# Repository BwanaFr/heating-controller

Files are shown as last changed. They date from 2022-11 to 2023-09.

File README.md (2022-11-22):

# Heating controller

## Presentation
This project is a IOT hardware heater controller for floor heat cumulating heaters (not sure about english term).
These heaters where mainly installed in France.
The principle is to store heat in the concrete floor during nights (when nuclear plants are free) to be restored during the day.

The heater can be controlled using MQTT using a Wi-Fi connection or using the integrated OLED display.
It is designed to be mounted on a DIN rail in an electrical cabinet.

## Hardware
Hardware design files are located in the hardware folder.
Schematics and PCB is designed using Kicad.

# Software
Microcontroller firmware is located in the software folder.
This is a PlatformIO project.

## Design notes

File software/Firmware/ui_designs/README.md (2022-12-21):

# About icons
Icons use in this project comes from Google Material Symbols [https://fonts.google.com/icons]

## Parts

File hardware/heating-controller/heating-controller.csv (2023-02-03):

Source: | C:\Temp\heating-controller\hardware\heating-controller\heating-controller.kicad_sch
Date: | 13/01/2023 11:20:34
Tool: | Eeschema (6.0.9)
Generator: | C:\Program Files\KiCad\6.0\bin\scripting\plugins/bom_csv_grouped_by_value.py
Component Count: | 36
Individual Components:
Item | Qty | Reference(s) | Value | LibPart | Footprint | Datasheet | Power | Type
 |  | C1 | 10uF | Device:C_Polarized | Capacitor_SMD:C_0805_2012Metric | ~
 |  | C2 | 10uF | Device:C_Polarized | Capacitor_SMD:C_0805_2012Metric | ~
 |  | C3 | 4.7uF | Device:C_Polarized | Capacitor_SMD:C_1206_3216Metric | ~
 |  | C4 | 1uF | Device:C | Capacitor_SMD:C_0603_1608Metric | ~
 |  | C5 | 150uF | Device:C_Polarized | Capacitor_THT:C_Radial_D10.0mm_H12.5mm_P5.00mm | ~
 |  | D1 | 1N4148WS | Diode:1N4148WS | Diode_SMD:D_SOD-323 | https://www.vishay.com/docs/85751/1n4148ws.pdf
 |  | D2 | LED | Device:LED_Small | LED_SMD:LED_0805_2012Metric | ~
 |  | D3 | ESD7371HT1G | Diode:SMF7V0A | Diode_SMD:D_SOD-323_HandSoldering | https://www.vishay.com/doc?85881
 |  | D4 | 1N4148WS | Diode:1N4148WS | Diode_SMD:D_SOD-323 | https://www.vishay.com/docs/85751/1n4148ws.pdf
 |  | F1 | T1A/300V | Device:Fuse | Fuse:Fuse_Littelfuse_372_D8.50mm | ~
 |  | F2 | T1A/300V | Device:Fuse | Fuse:Fuse_Littelfuse_372_D8.50mm | ~
 |  | J1 | Temperature_probes | Connector:Screw_Terminal_01x04 | TerminalBlock_Phoenix:TerminalBlock_Phoenix_MKDS-3-4-5.08_1x04_P5.08mm_Horizontal | ~
 |  | J2 | LilyGo T-Display S3 | Connector:Conn_01x12_Male | Connector_PinHeader_2.54mm:PinHeader_1x12_P2.54mm_Vertical | ~
 |  | J3 | Power connector | Connector:Screw_Terminal_01x07 | TerminalBlock_Phoenix:TerminalBlock_Phoenix_MKDS-3-7-5.08_1x07_P5.08mm_Horizontal | ~
 |  | J4 | EXT_LED | Connector_Generic:Conn_01x02 | Connector_PinHeader_2.54mm:PinHeader_1x02_P2.54mm_Vertical | ~
 |  | J5 | USER_LED | Connector_Generic:Conn_01x02 | Connector_PinHeader_2.54mm:PinHeader_1x02_P2.54mm_Vertical | ~
 |  | K1 | FINDER-32.21-x000 | Relay:FINDER-32.21-x000 | Relay_THT:Relay_SPDT_Finder_32.21-x000 | https://gfinder.findernet.com/assets/Series/355/S32EN.pdf
 |  | PS1 | AMEM5-5S277HAVZ | heating-controller:AMEM5-5S277HAVZ | heating-controller:Converter_ACDC_aimtec_AMEM5 | https://aimtec.com/site/Aimtec/files/Datasheet/HighResolution/amem5-277havz.pdf
 |  | Q1 | AO3400A | Transistor_FET:AO3400A | Package_TO_SOT_SMD:SOT-23 | http://www.aosmd.com/pdfs/datasheet/AO3400A.pdf
 |  | Q2 | AO3400A | Transistor_FET:AO3400A | Package_TO_SOT_SMD:SOT-23 | http://www.aosmd.com/pdfs/datasheet/AO3400A.pdf
 |  | R1 | 15k | Device:R | Resistor_SMD:R_0603_1608Metric | ~
 |  | R2 | 100k | Device:R | Resistor_THT:R_Axial_DIN0204_L3.6mm_D1.6mm_P5.08mm_Horizontal | ~
 |  | R3 | 100k | Device:R | Resistor_THT:R_Axial_DIN0204_L3.6mm_D1.6mm_P5.08mm_Horizontal | ~
 |  | R4 | 15k | Device:R | Resistor_SMD:R_0603_1608Metric | ~
 |  | R5 | 12 | Device:R | Resistor_THT:R_Axial_DIN0614_L14.3mm_D5.7mm_P15.24mm_Horizontal | ~ | 3W | Wirewound
 |  | R6 | 4.7k | Device:R | Resistor_SMD:R_0603_1608Metric | ~
 |  | R7 | 470 | Device:R | Resistor_SMD:R_0603_1608Metric | ~
 |  | R8 | 1k | Device:R | Resistor_SMD:R_0603_1608Metric | ~
 |  | R9 | 1k | Device:R | Resistor_SMD:R_0603_1608Metric | ~
 |  | R10 | 470 | Device:R | Resistor_SMD:R_0603_1608Metric | ~
 |  | R11 | 100k | Device:R | Resistor_SMD:R_0603_1608Metric | ~
 |  | R12 | 100k | Device:R | Resistor_SMD:R_0603_1608Metric | ~
 |  | R13 | 470 | Device:R | Resistor_SMD:R_0603_1608Metric | ~
 |  | RV1 | ERZE10A561 | Device:Varistor | Varistor:RV_Disc_D12mm_W7.5mm_P7.5mm | ~
 |  | RV2 | ERZE10A561 | Device:Varistor | Varistor:RV_Disc_D12mm_W7.5mm_P7.5mm | ~
 |  | U1 | H11AA1 | Isolator:H11AA1 | Package_DIP:DIP-6_W7.62mm | https://www.vishay.com/docs/83608/h11aa1.pdf
Collated Components:
Item | Qty | Reference(s) | Value | LibPart | Footprint | Datasheet | Power | Type
1 | 2 | C1, C2 | 10uF | Device:C_Polarized | Capacitor_SMD:C_0805_2012Metric | ~
2 | 1 | C3 | 4.7uF | Device:C_Polarized | Capacitor_SMD:C_1206_3216Metric | ~
3 | 1 | C4 | 1uF | Device:C | Capacitor_SMD:C_0603_1608Metric | ~
4 | 1 | C5 | 150uF | Device:C_Polarized | Capacitor_THT:C_Radial_D10.0mm_H12.5mm_P5.00mm | ~
5 | 2 | D1, D4 | 1N4148WS | Diode:1N4148WS | Diode_SMD:D_SOD-323 | https://www.vishay.com/docs/85751/1n4148ws.pdf
6 | 1 | D2 | LED | Device:LED_Small | LED_SMD:LED_0805_2012Metric | ~
7 | 1 | D3 | ESD7371HT1G | Diode:SMF7V0A | Diode_SMD:D_SOD-323_HandSoldering | https://www.vishay.com/doc?85881
8 | 2 | F1, F2 | T1A/300V | Device:Fuse | Fuse:Fuse_Littelfuse_372_D8.50mm | ~
9 | 1 | J1 | Temperature_probes | Connector:Screw_Terminal_01x04 | TerminalBlock_Phoenix:TerminalBlock_Phoenix_MKDS-3-4-5.08_1x04_P5.08mm_Horizontal | ~
10 | 1 | J2 | LilyGo T-Display S3 | Connector:Conn_01x12_Male | Connector_PinHeader_2.54mm:PinHeader_1x12_P2.54mm_Vertical | ~
11 | 1 | J3 | Power connector | Connector:Screw_Terminal_01x07 | TerminalBlock_Phoenix:TerminalBlock_Phoenix_MKDS-3-7-5.08_1x07_P5.08mm_Horizontal | ~
12 | 1 | J4 | EXT_LED | Connector_Generic:Conn_01x02 | Connector_PinHeader_2.54mm:PinHeader_1x02_P2.54mm_Vertical | ~
13 | 1 | J5 | USER_LED | Connector_Generic:Conn_01x02 | Connector_PinHeader_2.54mm:PinHeader_1x02_P2.54mm_Vertical | ~
14 | 1 | K1 | FINDER-32.21-x000 | Relay:FINDER-32.21-x000 | Relay_THT:Relay_SPDT_Finder_32.21-x000 | https://gfinder.findernet.com/assets/Series/355/S32EN.pdf
15 | 1 | PS1 | AMEM5-5S277HAVZ | heating-controller:AMEM5-5S277HAVZ | heating-controller:Converter_ACDC_aimtec_AMEM5 | https://aimtec.com/site/Aimtec/files/Datasheet/HighResolution/amem5-277havz.pdf
16 | 2 | Q1, Q2 | AO3400A | Transistor_FET:AO3400A | Package_TO_SOT_SMD:SOT-23 | http://www.aosmd.com/pdfs/datasheet/AO3400A.pdf
17 | 2 | R1, R4 | 15k | Device:R | Resistor_SMD:R_0603_1608Metric | ~
18 | 2 | R2, R3 | 100k | Device:R | Resistor_THT:R_Axial_DIN0204_L3.6mm_D1.6mm_P5.08mm_Horizontal | ~
19 | 1 | R5 | 12 | Device:R | Resistor_THT:R_Axial_DIN0614_L14.3mm_D5.7mm_P15.24mm_Horizontal | ~ | 3W | Wirewound
20 | 1 | R6 | 4.7k | Device:R | Resistor_SMD:R_0603_1608Metric | ~
21 | 3 | R7, R10, R13 | 470 | Device:R | Resistor_SMD:R_0603_1608Metric | ~
22 | 2 | R8, R9 | 1k | Device:R | Resistor_SMD:R_0603_1608Metric | ~
23 | 2 | R11, R12 | 100k | Device:R | Resistor_SMD:R_0603_1608Metric | ~
24 | 2 | RV1, RV2 | ERZE10A561 | Device:Varistor | Varistor:RV_Disc_D12mm_W7.5mm_P7.5mm | ~
25 | 1 | U1 | H11AA1 | Isolator:H11AA1 | Package_DIP:DIP-6_W7.62mm | https://www.vishay.com/docs/83608/h11aa1.pdf

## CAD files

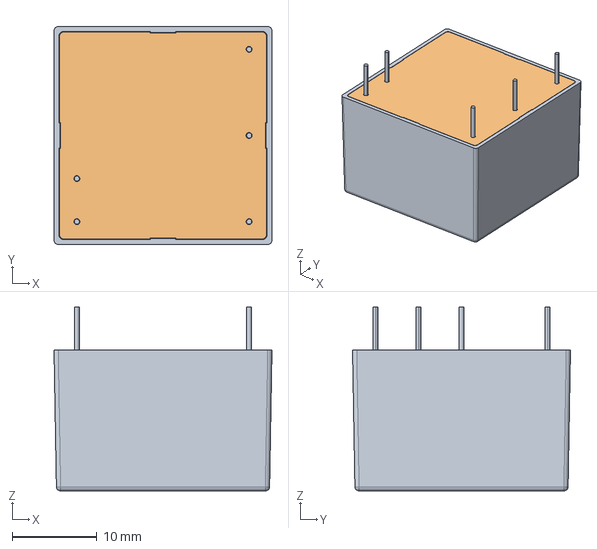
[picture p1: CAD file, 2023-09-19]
hardware/3d_models/tmps_05-105.stp
25.7 x 25.7 x 21.7 mm

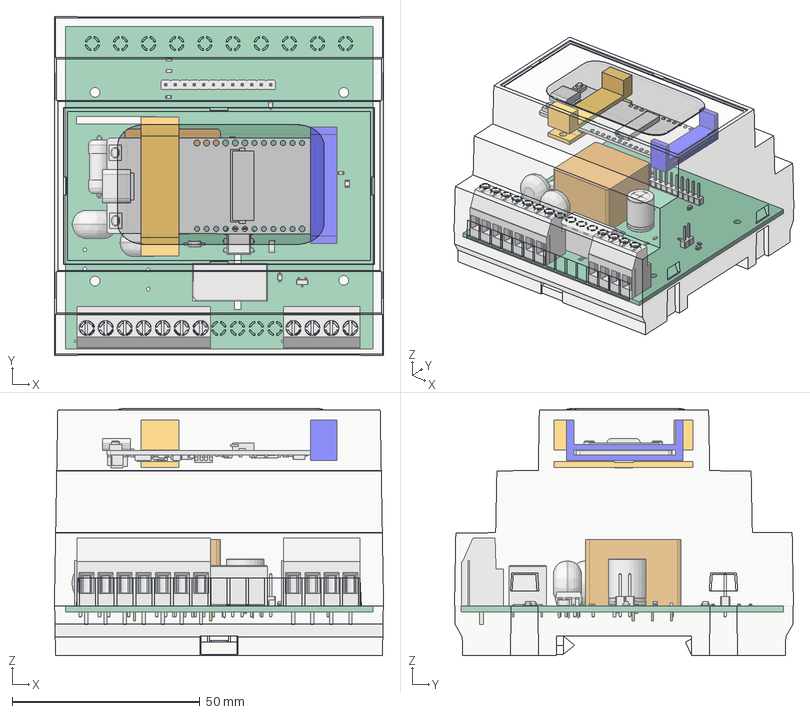
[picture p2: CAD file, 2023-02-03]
hardware/heating-controller-integration.FCStd
87.6 x 90.2 x 65.8 mm
NFP190B-01A_9_2_1
S-WATCH_TOUCH-SCREEN_15_1_1
T_DISPLAY_S3
Pcb_2b62
R6_R_0603_1608Metric_a486fa5abdc1 x 7
PS1_Pad001_cc960fdde001
C3_C_Radial_D100mm_H125mm_P500mm_71014cd09946
RV1_RV_Disc_D12mm_W75mm_P75mm_a3a09b8d229c x 2
J2_PinHeader_1x12_P254mm_Vertical_862bfcde2853
J3_TerminalBlock_Phoenix_MKDS_3_7_508_1x07_P508mm_Horizontal_bc2887fb8af6
D3_LED_0805_2012Metric_4455ae678b20
C1_C_1206_3216Metric_184f41baba65
D1_D_SOD_323_aa465fcb5bed x 3
K1_Relay_SPDT_Finder_32.21-x000_b01d047eb10a
J4_PinHeader_1x02_P254mm_Vertical_cb93ea696dab
C2_C_0603_1608Metric_af71e0b8cedf
J1_TerminalBlock_Phoenix_MKDS_3_4_508_1x04_P508mm_Horizontal_3f8e2a9aea9a
R5_R_Axial_DIN0614_L143mm_D57mm_P1524mm_Horizontal_10cb85c8e1dd
R3_R_Axial_DIN0204_L36mm_D16mm_P508mm_Horizontal_2cfa1f32dbe2 x 2
U1_DIP-6_W7.62mm_9f37de575c71
Q1_SOT_23_480f1ca98e1c
Support_antenna
Support_PCB
Support_PCB_top

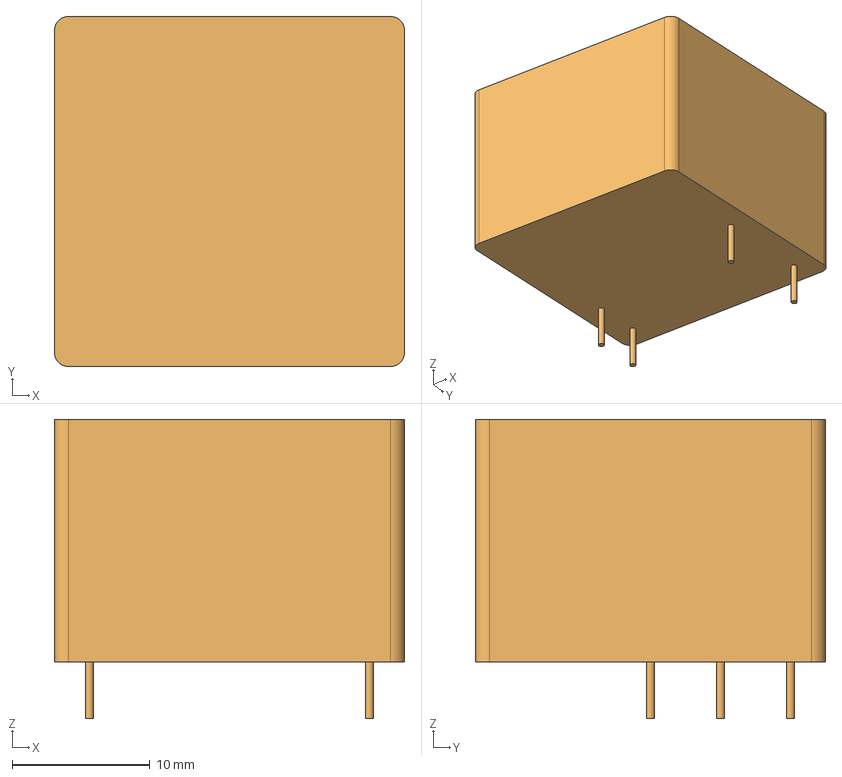
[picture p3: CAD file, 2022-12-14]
hardware/heating-controller/3d/Converter_ACDC_aimtec_AMEM5.step
25.4 x 25.4 x 21.7 mm

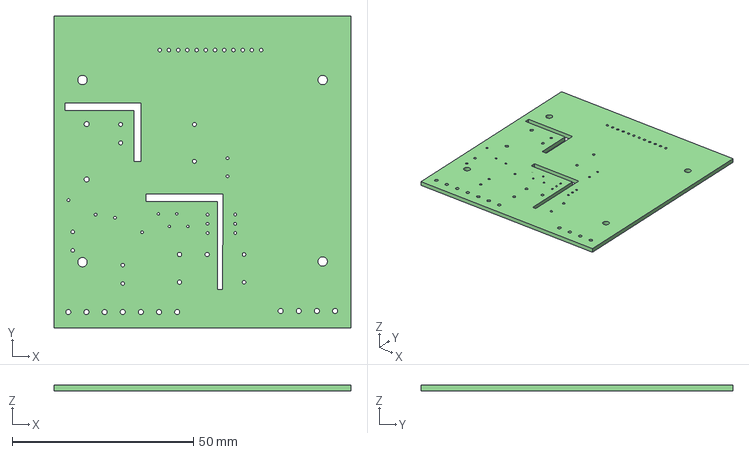
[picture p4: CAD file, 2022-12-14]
hardware/heating-controller/heating-controller.step
81.8 x 85.9 x 1.60 mm

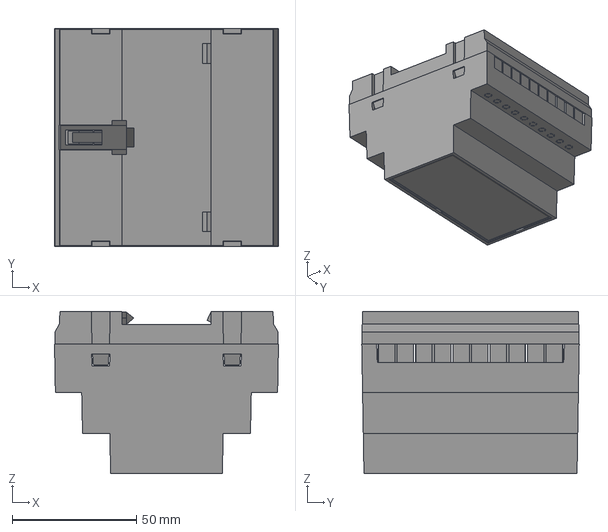
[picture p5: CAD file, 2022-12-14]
hardware/3d_models/z109_1.step
90.2 x 87.6 x 65.4 mm

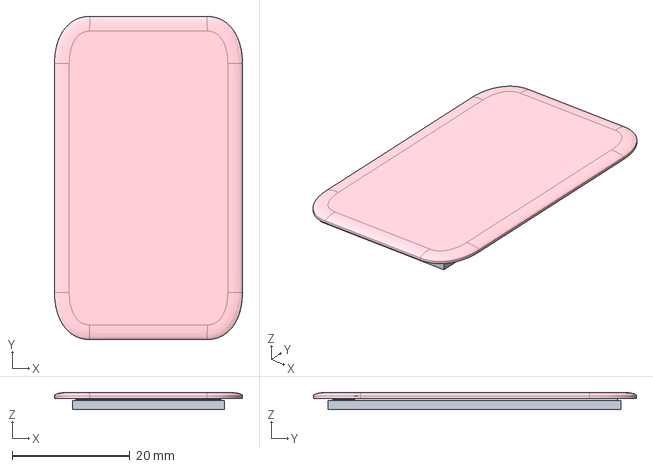
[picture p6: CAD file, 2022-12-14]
hardware/3d_models/glass_screen.stp
32.0 x 55.0 x 2.93 mm
NFP190B-01A_9_2_1
S-WATCH_TOUCH-SCREEN_15_1_1

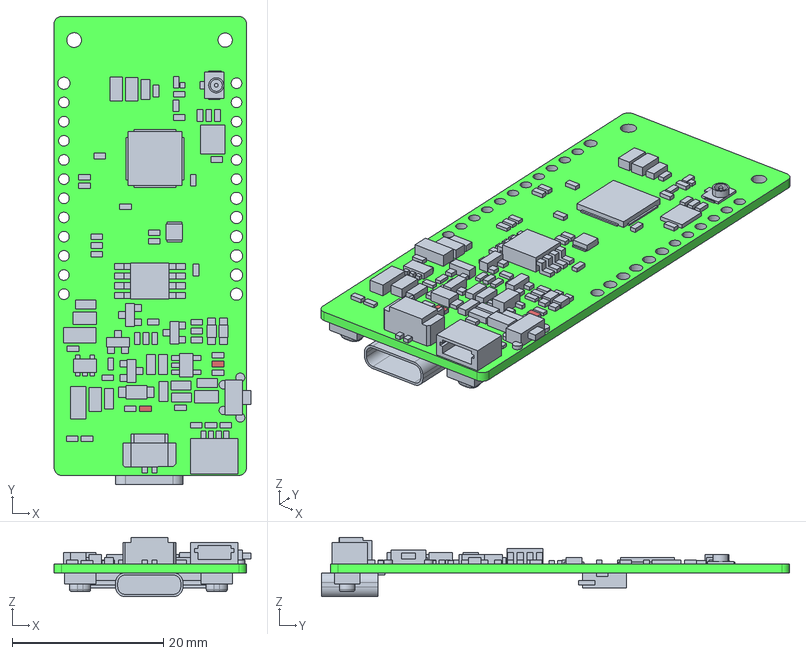
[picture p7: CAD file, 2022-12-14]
hardware/3d_models/t_display_s3.stp
26.1 x 62.0 x 7.86 mm

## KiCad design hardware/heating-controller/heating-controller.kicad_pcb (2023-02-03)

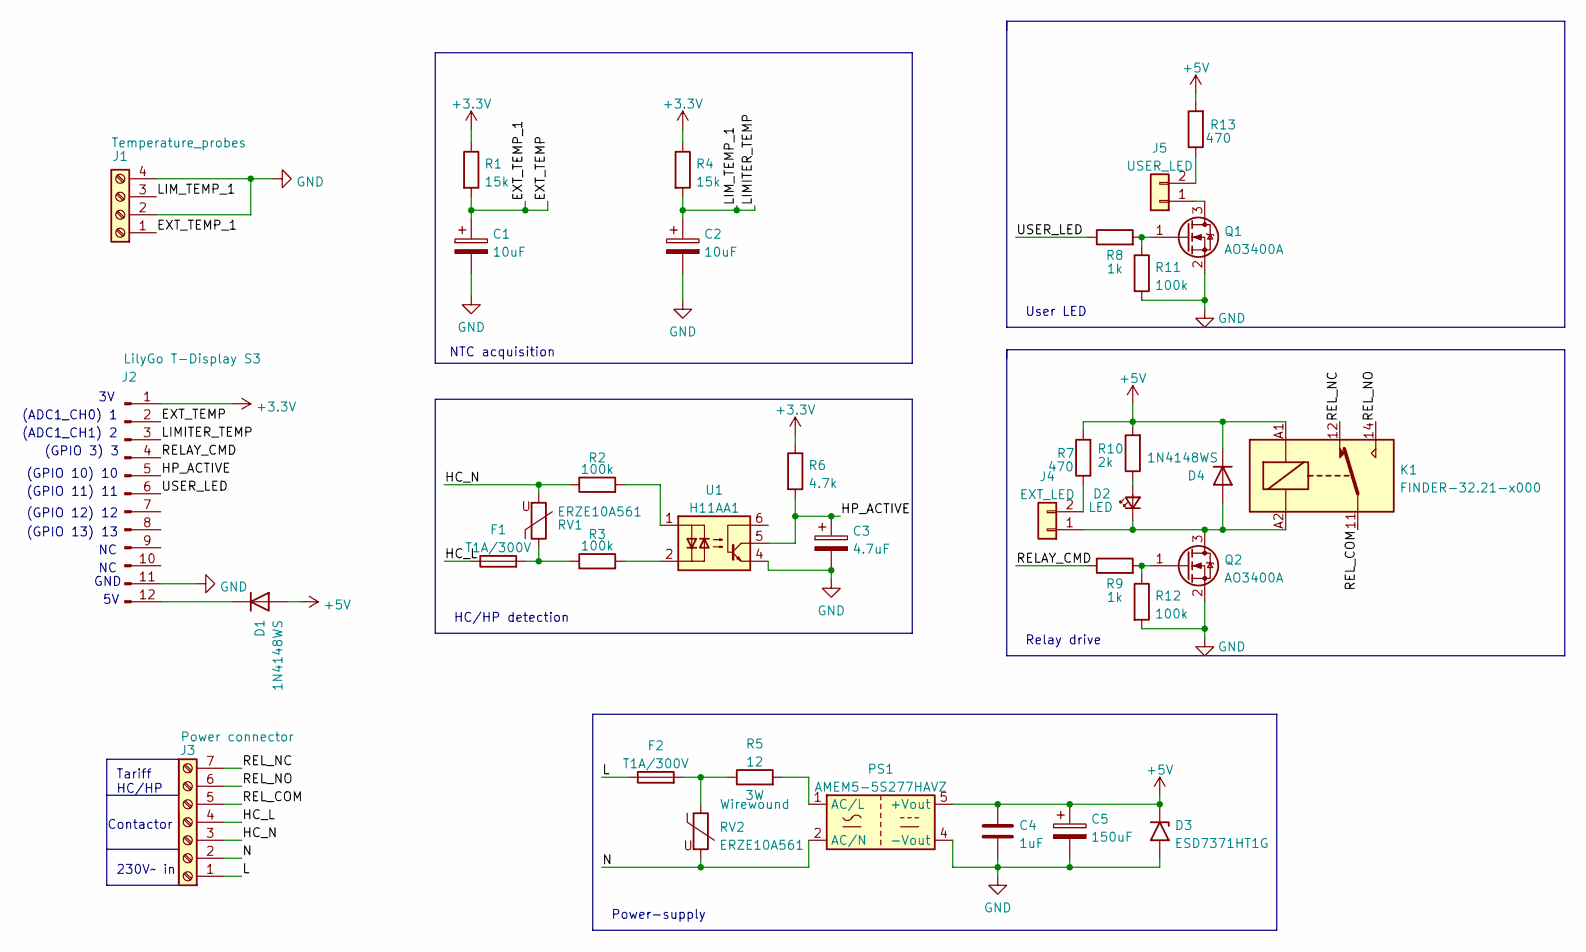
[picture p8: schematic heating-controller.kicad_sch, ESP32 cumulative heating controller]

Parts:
C1, C2: 10uF; C_0805_2012Metric
C3: 4.7uF; C_1206_3216Metric
C4: 1uF; C_0603_1608Metric
C5: 150uF; C_Radial_D10.0mm_H12.5mm_P5.00mm
D1, D4: 1N4148WS; D_SOD-323
D2: LED; LED_0805_2012Metric
D3: ESD7371HT1G; D_SOD-323_HandSoldering
F1, F2: T1A/300V; Fuse_Littelfuse_372_D8.50mm
J1: Temperature_probes; TerminalBlock_Phoenix_MKDS-3-4-5.08_1x04_P5.08mm_Horizontal
J2: LilyGo T-Display S3; PinHeader_1x12_P2.54mm_Vertical
J3: Power connector; TerminalBlock_Phoenix_MKDS-3-7-5.08_1x07_P5.08mm_Horizontal
J4: EXT_LED; PinHeader_1x02_P2.54mm_Vertical
J5: USER_LED; PinHeader_1x02_P2.54mm_Vertical
K1: FINDER-32.21-x000; Relay_SPDT_Finder_32.21-x000
PS1: AMEM5-5S277HAVZ; Converter_ACDC_aimtec_AMEM5
Q1, Q2: AO3400A; SOT-23
R1, R4: 15k; R_0603_1608Metric
R2, R3: 100k; R_Axial_DIN0204_L3.6mm_D1.6mm_P5.08mm_Horizontal
R5: 12; R_Axial_DIN0614_L14.3mm_D5.7mm_P15.24mm_Horizontal
R6: 4.7k; R_0603_1608Metric
R7, R13: 470; R_0603_1608Metric
R8, R9: 1k; R_0603_1608Metric
R10: 2k; R_0603_1608Metric
R11, R12: 100k; R_0603_1608Metric
RV1, RV2: ERZE10A561; RV_Disc_D12mm_W7.5mm_P7.5mm
U1: H11AA1; DIP-6_W7.62mm

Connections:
+3.3V: J2.1, R1.1, R4.1, R6.1
+5V: C4.1, C5.1, D1.2 (A), D3.1 (A1), D4.1 (K), K1.A1, PS1.5 (+Vout), R7.2, R10.2, R13.2
/EXT_TEMP: C1.1, J1.1, J2.2, R1.2
/HC_L: F1.1, J3.4
/HC_N: J3.3, R2.1, RV1.2
/HP_ACTIVE: C3.1, J2.5, R6.2, U1.5
/L: F2.1, J3.1
/LIMITER_TEMP: C2.1, J1.3, J2.3, R4.2
/N: J3.2, PS1.2 (AC/N), RV2.2
/RELAY_CMD: J2.4, R9.1
/REL_COM: J3.5, K1.11
/REL_NC: J3.7, K1.12
/REL_NO: J3.6, K1.14
/USER_LED: J2.6, R8.1
unnamed: D1.1 (K), J2.12
unnamed: D2.1 (K), D4.2 (A), J4.1, K1.A2, Q2.3 (D)
unnamed: D2.2 (A), R10.1
unnamed: F1.2, R3.1, RV1.1
unnamed: F2.2, R5.1, RV2.1
unnamed: J4.2, R7.1
unnamed: J5.1, Q1.3 (D)
unnamed: J5.2, R13.1
unnamed: PS1.1 (AC/L), R5.2
unnamed: Q1.1 (G), R8.2, R11.1
unnamed: Q2.1 (G), R9.2, R12.1
unnamed: R2.2, U1.1
unnamed: R3.2, U1.2

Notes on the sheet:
(GPIO 10) 10
(GPIO 12) 12
User LED
(GPIO 13) 13
Contactor
GND
Power-supply
NTC acquisition
Tariff HC/HP
(GPIO 11) 11
(ADC1_CH1) 2
230V~ in
(GPIO 3) 3
(ADC1_CH0) 1
Relay drive
HC/HP detection

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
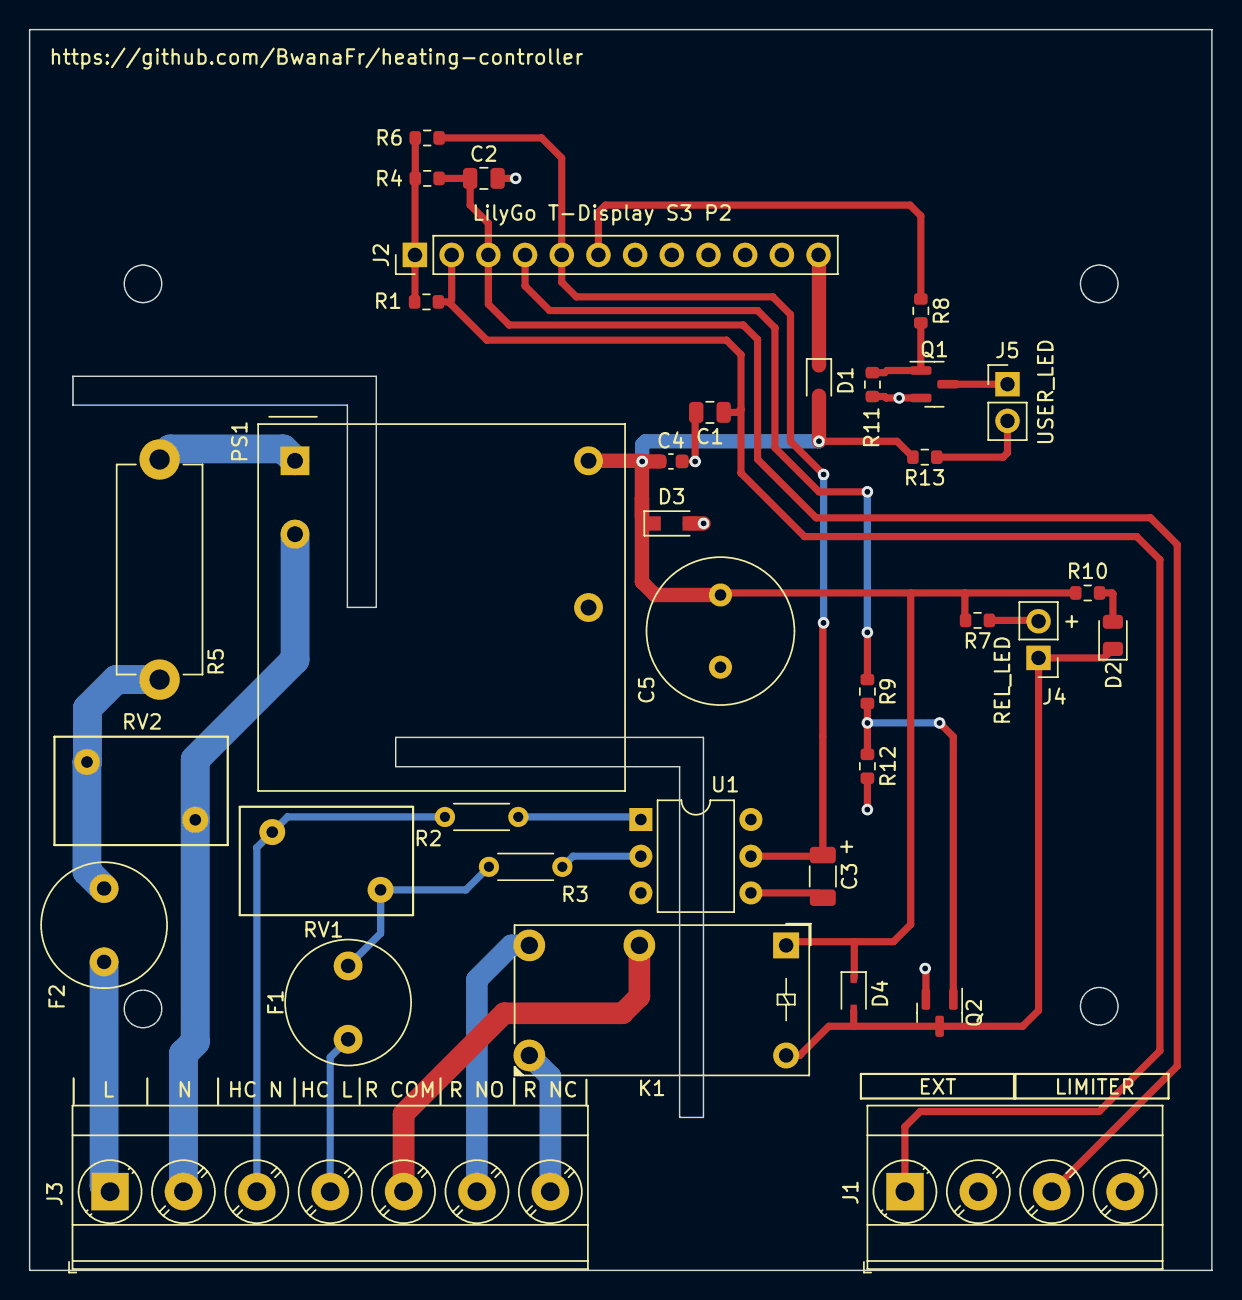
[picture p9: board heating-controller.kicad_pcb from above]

Board: 2 copper layers, 81.8 x 85.9 mm, 36 parts (0 on the bottom side), 28 nets.

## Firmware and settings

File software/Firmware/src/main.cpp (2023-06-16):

/**
 *  Cumulative heater controler
 *  Alternative regulator for Delta Dore 125n
 *  https://github.com/BwanaFr/heating-controller
**/


#include <Arduino.h>

#include "screen.h"
#include "inout.h"
#include "lvgl.h"
#include "ui/ui.h"
#include "pin_config.h"
#include "process.h"
#include "parameters.h"
#include "mqtt.h"

//For OTA update
#include <Update.h>

//MQTT includes
#include <PubSubClient.h>
#include <ArduinoJson.h>

//ESPEasyCfg objects
AsyncWebServer server(80);
ESPEasyCfg captivePortal(&server, "Heater");
Parameters parameters;

//MQTT objects
MQTT mqtt;

//Other variables
static bool systemReady = false;            // True when system is ready
Process process;                            // Class used to compute the heating value
size_t otaContentLenght;                    // Size of the OTA update file
/**
 * Callback to get captive-portal messages
*/
void captive_portal_message(const char* msg, ESPEasyCfgMessageType type) {
  Serial.println(msg);
}

/**
 * Callback from captive portal when state has changed
*/
void captive_portal_state(ESPEasyCfgState state) {
  if(state == ESPEasyCfgState::Reconfigured){
    Parameters::getInstance()->captivePortalReconfigured();  
  }
}

/**
 * Setups the captive portal
 * 
*/
void captive_portal_setup( void * parameter ) {
  //Configure captive portal
  parameters.init(&captivePortal);
  captivePortal.setLedPin(PIN_USER_LED);
  captivePortal.setMessageHandler(captive_portal_message);
  captivePortal.setStateHandler(captive_portal_state);
  //Start our captive portal (if not configured)
  //At first usage, you will find a new WiFi network named "Heater"
  captivePortal.begin();
  //Serve web pages
  server.begin();
  //System is ready!
  systemReady = true;
  //Terminates the FreeRTOS tasks
  vTaskDelete( NULL );
}

/**
 * Setups OTA update
*/
void setup_ota_update() {
  server.on("/www/update", HTTP_GET, [](AsyncWebServerRequest *request){
    request->send(200, "text/html", "<html><body><form method='POST' action='/www/update' enctype='multipart/form-data'><input type='file' name='update'><input type='submit' value='Update'></form></body></html>");
  });
  server.on("/www/update", HTTP_POST,
    [](AsyncWebServerRequest *request) {},
    [](AsyncWebServerRequest *request, const String& filename, size_t index, uint8_t *data, size_t len, bool final) {
                    if (!index){
                      Serial.println("Update");
                      otaContentLenght = request->contentLength();
                      // if filename includes spiffs, update the spiffs partition
                      int cmd = (filename.indexOf("spiffs") > -1) ? U_SPIFFS : U_FLASH;
                      if (!Update.begin(otaContentLenght, cmd)) {
                        Update.printError(Serial);
                      }
                    }

                    if (Update.write(data, len) != len) {
                      Update.printError(Serial);
                    } else {
                      Serial.printf("Progress: %d%%\n", (Update.progress()*100)/Update.size());
                    }

                    if (final) {
                      AsyncWebServerResponse *response = request->beginResponse(302, "text/plain", "Please wait while the device reboots");
                      response->addHeader("Refresh", "20");  
                      response->addHeader("Location", "/");
                      request->send(response);
                      if (!Update.end(true)){
                        Update.printError(Serial);
                      } else {
                        Serial.println("Update complete");
                        Serial.flush();
                        ESP.restart();
                      }
                    }
                  }
  );
}

/**
 * Arduino Setup method
*/
void setup() {
  Serial.begin(115200);
  Serial.println("Heating-controller alive!");
  //Setup the LCD screen  
  setup_screen();
  //Setup I/O
  setup_inputs_outputs();
  //Setup OTA
  setup_ota_update();

  //Create a task to initialize the Wifi (take long time, so we keep LVGL alive)
  xTaskCreate(
            captive_portal_setup,          /* Task function. */
            "WifiSetup",        /* String with name of task. */
            8*1024,            /* Stack size in bytes. */
            NULL,             /* Parameter passed as input of the task */
            1,                /* Priority of the task. */
            NULL);            /* Task handle. */
}

static unsigned long lastCheck = 0;
static int temp = 0;
static bool prevSystemReady = false;

void loop() {
  unsigned long now = millis();
  
  //LVGL and screen management loop
  loop_screen(systemReady);

  //If captive portal is ready, load parameters
  if(systemReady && !prevSystemReady){
    Parameters::getInstance()->captivePortalReconfigured();
  }

  if(systemReady){
    //Do it every second, it's enough
    if((now-lastCheck) >= 1000){
      lastCheck = now;
      double extTemp = getExternalTemperature();
      double floorTemp = getFloorTemperature();
      bool peakTime = getTariffInput();
      bool relay = process.setIOState(extTemp, floorTemp, peakTime);
      setRelay(relay);
    }
    mqtt.loop();
    
    parameters.loop();
  }

  prevSystemReady = systemReady;
  delayMicroseconds(100);
}

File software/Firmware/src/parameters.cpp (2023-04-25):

#include "parameters.h"
#include "process.h"
#include "inout.h"
#include "mqtt.h"
#include <Arduino.h>

//Do we really update UI here?
#include <ui/events.h>
#include "lvgl.h"

#define PROFILE_OFF_INDEX 0
#define PROFILE_ECO_INDEX 1
#define PROFILE_STD_INDEX 2


Parameters* Parameters::instance_ = nullptr;
/**
 * Best constructor ever :)
*/
Parameters::Parameters() :
    mqttParamGrp_("MQTT"), mqttServer_(mqttParamGrp_, "mqttServer", "MQTT server", "", "server.local"),
    mqttUser_(mqttParamGrp_, "mqttUser", "MQTT user", "user"), mqttPass_(mqttParamGrp_, "mqttPass", "MQTT password", ""),
    mqttPort_(mqttParamGrp_, "mqttPort", "MQTT port", 1883), mqttName_(mqttParamGrp_, "mqttName", "MQTT name", "Heater", "", "{\"required\":\"\"}"),
    heatingParamGrp_("Heating"),
    currentProfile_(heatingParamGrp_, "heatProfile", "Heating profile", "Off;Eco;Standard", "Off"),
    timeBase_(heatingParamGrp_, "heatTimeBase", "Heating time-base [s]", 60),
    tempLimit_(heatingParamGrp_, "tempLimit", "Floor temperature limit [C]", 35),
    profileEcoParamGrp_("Eco profile"),
    profileEcoHParamGrp_("Peak time"),
    profileEcoHOffTemp_(profileEcoHParamGrp_, "profileEcoHOffTemp", "Off temperature", 5.0),
    profileEcoHFullTemp_(profileEcoHParamGrp_, "profileEcoHFullTemp", "Full temperature", 0.0),
    profileEcoLParamGrp_("Off-peak time"),
    profileEcoLOffTemp_(profileEcoLParamGrp_, "profileEcoLOffTemp", "Off temperature", 8.0),
    profileEcoLFullTemp_(profileEcoLParamGrp_, "profileEcoLFullTemp", "Full temperature", 3.0),
    profileStdParamGrp_("Standard profile"),
    profileStdHParamGrp_("Peak time"),
    profileStdHOffTemp_(profileStdHParamGrp_, "profileStdHOffTemp", "Off temperature", 8.0),
    profileStdHFullTemp_(profileStdHParamGrp_, "profileStdHFullTemp", "Full temperature", 3.0),
    profileStdLParamGrp_("Off-peak time"),
    profileStdLOffTemp_(profileStdLParamGrp_, "profileStdLOffTemp", "Off temperature", 12.0),
    profileStdLFullTemp_(profileStdLParamGrp_, "profileStdLFullTemp", "Full temperature", 5.0),
    systemParamGrp_("System"),
    adcRefVoltage_(systemParamGrp_, "adcRefVoltage", "ADC reference voltage [mV]", 3112, "", "{\"min\":\"0\", \"max\":\"3500\"}"),
    adcAveraging_(systemParamGrp_, "adcAveraging", "ADC averaging [samples]", 100, "", "{\"min\":\"0\", \"max\":\"500\"}"),
    lastParameterChange_(0)
{
    instance_ = this;
}

void Parameters::loop()
{
    unsigned long now = millis();
    //Delayed parameter saving
    if((lastParameterChange_ != 0) && ((now-lastParameterChange_)>delayedParameterSaving)){
      lastParameterChange_ = 0;
      if(portal_){
        portal_->saveParameters();
        Serial.println("Saving parameters!");
      }
    }
}
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

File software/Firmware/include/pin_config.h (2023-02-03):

#pragma once


/* LCD CONFIG */
#define LCD_PIXEL_CLOCK_HZ   (6528000) //(10 * 1000 * 1000)
// The pixel number in horizontal and vertical
#define LCD_H_RES            320
#define LCD_V_RES            170
#define LVGL_LCD_BUF_SIZE            (LCD_H_RES * LCD_V_RES)

/*ESP32S3*/
#define PIN_LCD_BL                   38

#define PIN_LCD_D0                   39
#define PIN_LCD_D1                   40
#define PIN_LCD_D2                   41
#define PIN_LCD_D3                   42
#define PIN_LCD_D4                   45
#define PIN_LCD_D5                   46
#define PIN_LCD_D6                   47
#define PIN_LCD_D7                   48

#define PIN_POWER_ON                 15

#define PIN_LCD_RES                  5
#define PIN_LCD_CS                   6
#define PIN_LCD_DC                   7
#define PIN_LCD_WR                   8
#define PIN_LCD_RD                   9

#define PIN_BUTTON_1                 0
#define PIN_BUTTON_2                 14
#define PIN_BAT_VOLT                 4

#define PIN_IIC_SCL                  17
#define PIN_IIC_SDA                  18

#define PIN_TOUCH_INT                16
#define PIN_TOUCH_RES                21

/* Heater I/O */
#define PIN_EXT_TEMP                 1
#define PIN_FLOOR_TEMP               2
#define PIN_RELAY                    3
#define PIN_TARIFF                   10
#define PIN_USER_LED                 11

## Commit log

2022-11-23 First PCB, needs to be checked
    [heating-controller.kicad_pcb, heating-controller.kicad_sch]
2022-12-21 Added 10uF capacitors to NTC
    [heating-controller-integration.FCStd, heating-controller.kicad_pcb, heating-controller.kicad_sch]
2023-03-23 Added process for controlling relay
2023-03-23 Fixed boolean display labels
    [inout.cpp]
2023-05-02 Fixed back button handling
    [more.cpp, screen.cpp, setup.cpp]
2023-05-03 Fixed screen unblanking artefacts
    [screen.cpp]
2023-05-23 Added T-Display board
2023-05-26 Removed USB serial device, call LV more often
2023-06-16 Trying to fix screen blanking
    [main.cpp, more.cpp, screen.cpp]
2023-09-19 Improving ADC precision
    [tmps_05-105.stp]
